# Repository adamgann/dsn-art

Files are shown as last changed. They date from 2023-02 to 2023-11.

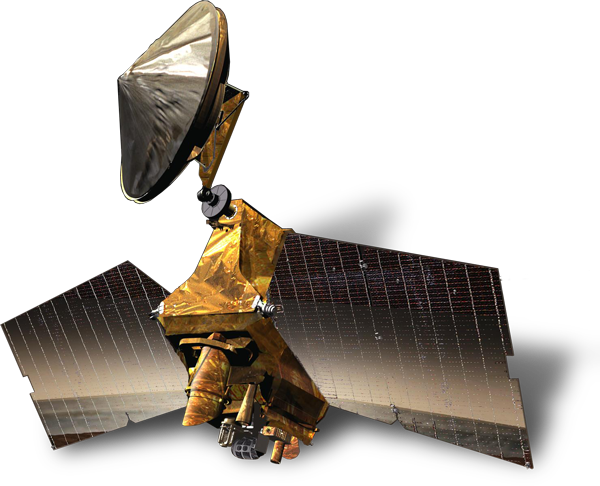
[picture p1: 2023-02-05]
images/source/mro.png

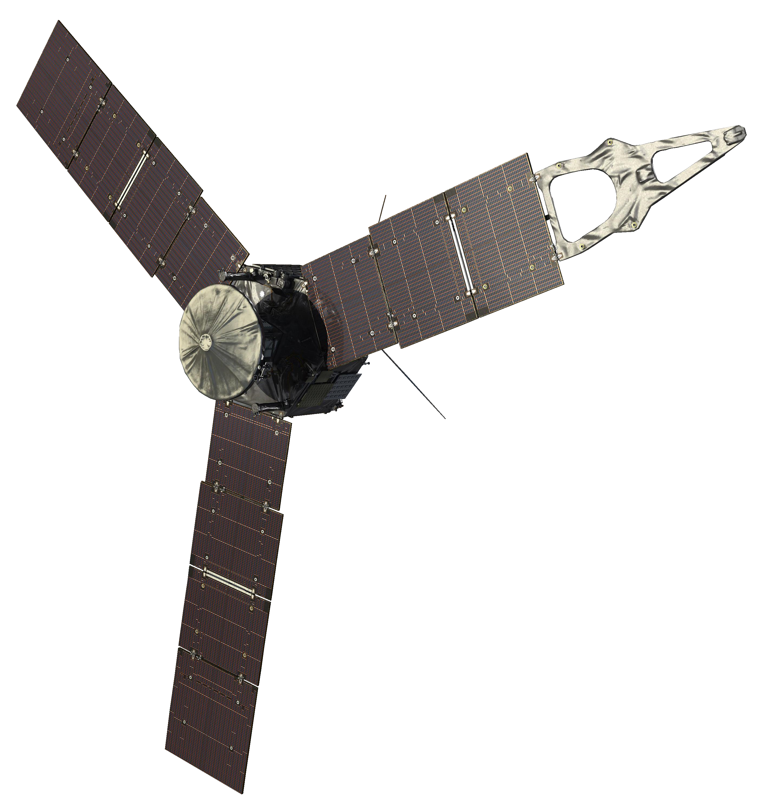
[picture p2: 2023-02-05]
images/source/juno.png

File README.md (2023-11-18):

# dsn-art
Live wall art of spacecraft communicating over NASA's Deep Space Network. By Adam Gannon.

### Repo Structure
- `eagle/` contains PCB files for the Pi HAT in Eagle CAD
- `images/` contains spacecraft images used to make cutouts
- `python/` contains the `dsnleds` package which runs on the Pi. See README for 
code setup.

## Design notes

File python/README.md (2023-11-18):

Code which executes on the Pi to power LED display. Parser module based on github.com/russss/pydsn

### Prerequisites
Code written and tested on RasPi Zero W. Requires the CircuitPython NeoPixel library running on RasPi. Follow [Adafruit instructions](https://learn.adafruit.com/circuitpython-on-raspberrypi-linux/overview). When calling functions in this library you must run as root.

### Install
Installation with pip gives the `dsn-leds` package. We'll need a global install so the script can be run as root. Pip's warning about sudo install can be ignored, running this code is really the only thing this board is doing.

```
cd dsn-art/python
sudo pip install .
```
Add this to `/etc/rc.local` to start a background process on startup

```
dsn-leds &
```

### Test 
The LED test module will cycle through each spacecraft on the board
```
python -m tests.test_leds
```

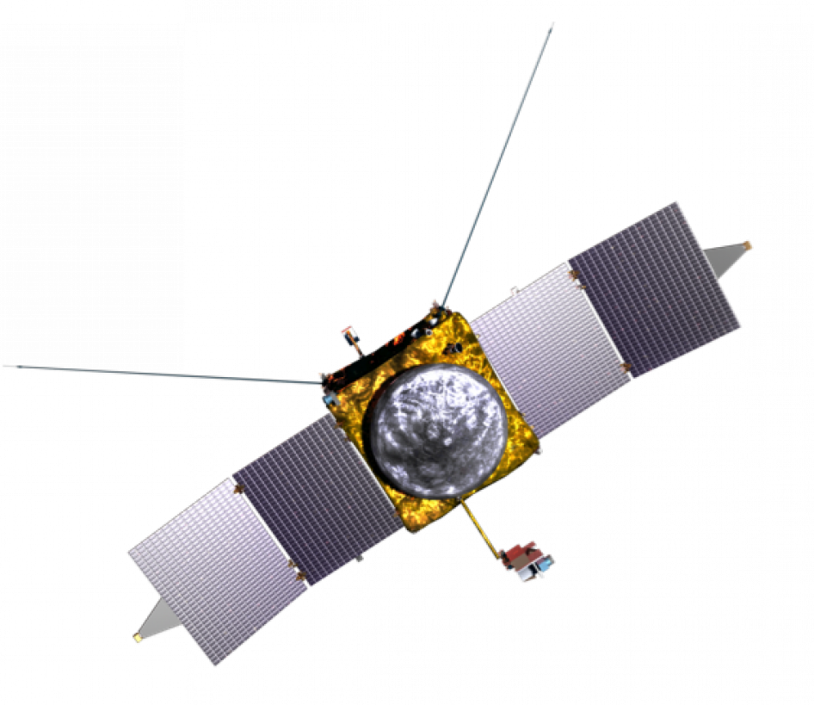
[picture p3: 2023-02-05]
images/source/maven.png

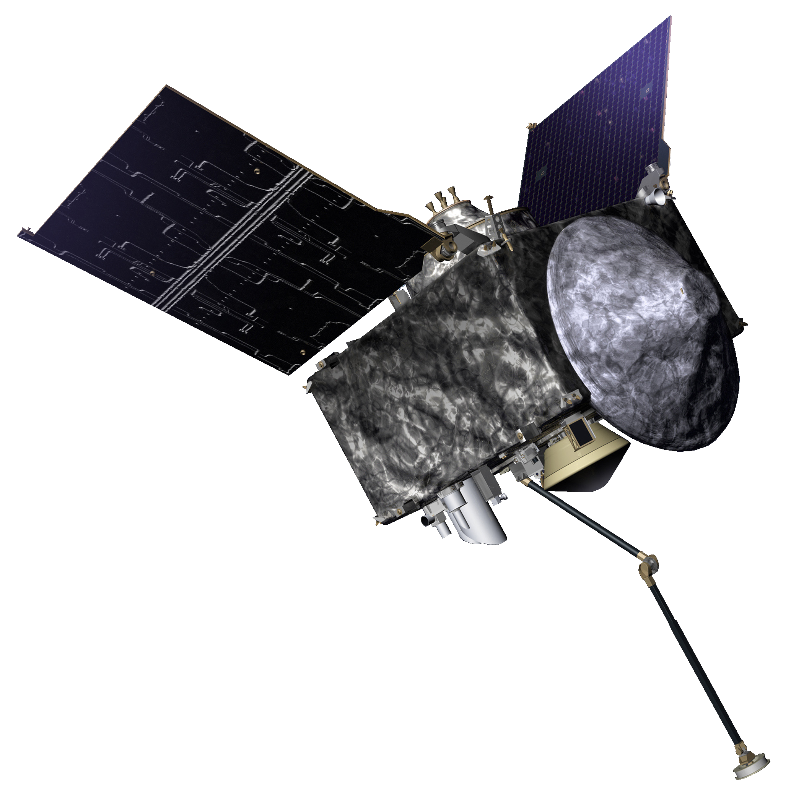
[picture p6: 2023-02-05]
images/source/osiris.png

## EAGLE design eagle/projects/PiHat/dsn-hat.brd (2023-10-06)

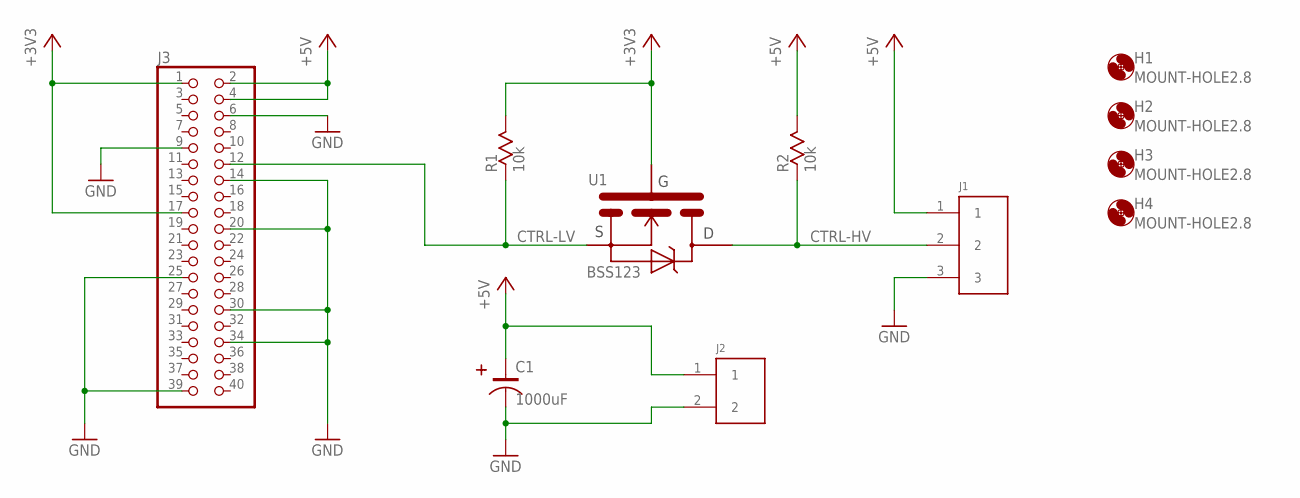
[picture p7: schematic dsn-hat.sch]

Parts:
C1: 1000uF; CAP-TH
H1, H2, H3, H4: MOUNT-HOLE2.8; 2,8
J1: TERM-TH-3TERM-TH-3; TERM-TH-3
J2: TERM-TH-2TH2; TERM-TH-2
J3: PINHD-2X20; 2X20
R1, R2: 10k; R0805
U1: BSS123; SOT23

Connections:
+3V3: J3.1, J3.17, R1.1, U1.1 (G)
+5V: C1.POS, J1.1, J2.1, J3.2, J3.4, R2.1
CTRL-HV: J1.2, R2.2, U1.3 (D)
CTRL-LV: J3.12, R1.2, U1.2 (S)
GND: C1.NEG, J1.3, J2.2, J3.6, J3.9, J3.14, J3.20, J3.25, J3.30, J3.34, J3.39

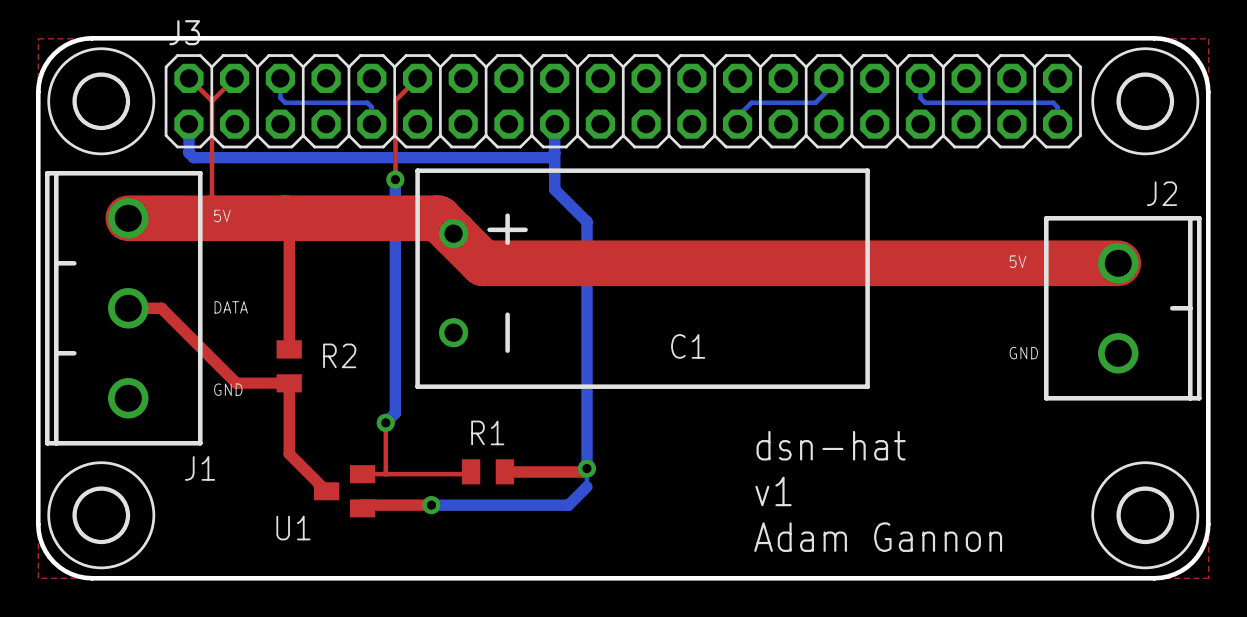
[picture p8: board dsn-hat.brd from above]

Board: 2 copper layers, 65.0 x 30.0 mm, 11 parts (0 on the bottom side), 5 nets.

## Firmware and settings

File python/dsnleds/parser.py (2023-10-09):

"""Parse DSN webpage, adapted from github.com/russss/pydsn"""
from __future__ import division, absolute_import, print_function, unicode_literals
import logging
from decimal import Decimal
import time
import requests
import logging
import dateutil.parser
from lxml import etree

logger = logging.getLogger(__name__)

def to_decimal(value):
    if value == "" or value == "null":
        return None
    return Decimal(value)


class DSNParser(object):
    def __init__(self):
        self.log = logging.getLogger(__name__)
        self.http_session = requests.Session()

    def get_url(self):
        return "https://eyes.jpl.nasa.gov/dsn/data/dsn.xml?r=%s" % (int)(
            time.time() / 5
        )

    def get_config_url(self):
        return "https://eyes.jpl.nasa.gov/dsn/config.xml"

    def fetch_data(self):
        url = self.get_url()
        self.log.debug("Fetching %s" % url)
        response = self.http_session.get(url)
        doc = etree.fromstring(response.content)
        dishes = doc.xpath("/dsn/dish")
        result = {}
        for dish in dishes:
            dish_name, data = self.parse_dish(dish)
            result[dish_name] = data
        return result

    def parse_dish(self, dish):
        data = {
            "azimuth_angle": to_decimal(dish.get("azimuthAngle")),  # Degrees
            "elevation_angle": to_decimal(dish.get("elevationAngle")),  # Degrees
            "wind_speed": to_decimal(dish.get("windSpeed")),  # km/h
            "mspa": dish.get("isMSPA") == "true",  # Multiple Spacecraft Per Aperture
            "array": dish.get("isArray") == "true",  # Dish is arrayed
            "ddor": dish.get("isDDOR") == "true",  # Delta-Differenced One Way Range
            #"created": dateutil.parser.parse(dish.get("created")),
            #"updated": dateutil.parser.parse(dish.get("updated")),
            "targets": {},
            "up_signal": [],
            "down_signal": [],
        }
        for target in dish.findall("target"):
            name, target_data = self.parse_target(target)
            data["targets"][name] = target_data

        for up_signal in dish.findall("upSignal"):
            data["up_signal"].append(self.parse_signal(up_signal))

        for down_signal in dish.findall("downSignal"):
            data["down_signal"].append(self.parse_signal(down_signal))

        if "DSN" in data["targets"]:
            # A target of 'DSN' seems to indicate that the dish is out of service
            data["targets"] = {}
            data["up_signal"] = []
            data["down_signal"] = []
            data["online"] = False
        else:
            data["online"] = True

        return dish.get("name"), data

    def parse_target(self, target):
        data = {
            "id": int(target.get("id")),
            "up_range": Decimal(target.get("uplegRange")),  # Up leg range, meters
            "down_range": Decimal(target.get("downlegRange")),  # Down leg range, meters
            "rtlt": Decimal(target.get("rtlt")),  # Round-trip light time, in seconds
        }
        return target.get("name"), data

    def parse_signal(self, signal):
        if signal.get("spacecraft") == "DSN":
            # DSN is a bogus spacecraft
            return None
        data = {
            "type": signal.get("signalType"),  # "data", "carrier", "ranging", or "none"
            "debug": signal.get("signalTypeDebug"),  # Interesting signal debug info
            "spacecraft": signal.get("spacecraft"),
        }

        if signal.get("power") == "":
            data["power"] = None
        else:
            data["power"] = to_decimal(
                signal.get("power")
            )  # Power (in dBm for downlink, kW for uplink.)

        if signal.get("frequency") == "" or signal.get("frequency") == "none":
            data["frequency"] = None
        else:
            data["frequency"] = to_decimal(
                signal.get("frequency")
            )  # Frequency (Hz). Always present but may be wrong if type is none

        if signal.get("dataRate") == "":
            data["data_rate"] = None
        else:
            data["data_rate"] = to_decimal(
                signal.get("dataRate")
            )  # Data rate, bits per second

        return data

    def fetch_config(self):
        url = self.get_config_url()
        self.log.debug("Fetching config %s" % url)
        response = self.http_session.get(url)
        doc = etree.fromstring(response.content)
        spacecraft = self.fetch_spacecraft(
            doc.xpath("/config/spacecraftMap/spacecraft")
        )
        sites = self.fetch_sites(doc.xpath("/config/sites/site"))
        return sites, spacecraft

    def fetch_spacecraft(self, spacecraft):
        data = {}
        for craft in spacecraft:
            data[craft.get("name")] = craft.get("friendlyName")
        return data

    def fetch_sites(self, sites):
        data = {}
        for site in sites:
            dishes = {}
            for dish in site.findall("dish"):
                dishes[dish.get("name")] = {
                    "friendly_name": dish.get("friendlyName"),
                    "type": dish.get("type"),
                }
            data[site.get("name")] = {
                "friendly_name": site.get("friendlyName"),
                "dishes": dishes,
            }
        return data


if __name__ == "__main__":
    parser = DSNParser()
    from pprint import pprint

    pprint(parser.fetch_data())

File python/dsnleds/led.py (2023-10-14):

"""Set groups of LEDs to certain colors based on status."""
from enum import Enum
import logging

# Imports for Adafruit Neopixels
import board
import neopixel

# Neopixel strip is cut to 30 LEDs
NUM_LEDS = 30

logger = logging.getLogger(__name__)

class Status(Enum):
    """RGB triplet for each type of spacecraft status."""
    OFF = (0, 0, 0)
    UP_DATA = (0, 235, 145)
    DOWN_DATA = (0, 130, 235)
    BOTH_DATA = (225, 0, 235)
    UP_CARRIER = (0, 0, 235)
    DOWN_CARRIER = (0, 0, 235)
    BOTH_CARRIER = (0, 0, 235)


class Leds:
    """Manipulate LEDs."""
    
    def __init__(self):
        self._pixels = neopixel.NeoPixel(board.D18, 30)

    def all_off(self):
        """Set all 30 LEDs off."""
        self.set_all(Status.OFF)

    def set_all(self, status):
        """Set all LEDs to a given status."""
        self._pixels.fill((status.value))

    def set_group(self, pins, status):
        """Set each pin in the list pins to the
        RGB triplet contained in status."""
        for pin in pins:
            self._pixels[pin] = status.value
            logger.debug(f"LED #{pin} to {status.value}")

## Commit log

2021-01-10 Started script to test LED segments.
2021-12-31 First draft of PCB in Eagle.
    [dsn-hat.brd, dsn-hat.sch]
2023-10-06 Update board files, as sent to fab shop.
    [dsn-hat.brd]
2023-10-06 Updated pin map for actual hardware.
2023-10-07 Reworking classes to be much cleaner.
    [led.py, mapping.py]
2023-10-07 Better filtering logic.
2023-10-14 Fix LED logic.
2023-10-15 Turning LEDs off when outside time band.
2023-11-18 Added test script that randomly lights LEDs for offline demo.
